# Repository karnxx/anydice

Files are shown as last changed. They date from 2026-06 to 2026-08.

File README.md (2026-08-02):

# Anydice
so this is a dice which can basically roll any number, it uses a xiao esp32c3, an oled, mpu 6040. u can set the max dice roll possibility and then shake and roll it like normal to produce a randomly generated number.

i made this project as my dnd dices wud get lost alot, and it couldnt roll some numbers, and using traditional rng online is distracting.

# WORKING
- so with the button you can set the max digit to roll. then u can shake the dice and actually roll it(mpu6050) to produce a final number on the oled, which is a random number between 0 and tht max digit. 

# PCB
- custom pcb via kicad, files [here](https://github.com/karnxx/anydice/tree/main/pcb)
- the pcb is mounted in the dice via screws, and the oled is mounted on the pcb with screws and spacers.




# [CAD](https://gmail4855044.autodesk360.com/g/shares/SH90d2dQT28d5b602811d05a79f94586e235)
- cadded via fusion360, files [here](https://github.com/karnxx/anydice/tree/main/cad)





# BOM
- bom is [here](https://docs.google.com/spreadsheets/d/12x69VHwHTzA7m8ty_oVYzZqYExIBdv50qRqhHhF5CHE/edit?usp=sharing)


| Part | Qty | Cost (₹) | Link |
|---|-----:|---:|---|
| xiaoesp32c3 | 1 | 146.00 | https://robocraze.com/products/esp32-c3-mini-development-board-unsoldered |
| mpu6040 | 1 | 154.00 | https://robocraze.com/products/mpu-6050-triple-axis-accelerometer-gyroscope-module |
| right angle tactile pushbutton | 1 | 10.00 | https://probots.co.in/mini-push-switch-right-angled.html |
| tp4056 battery management | 1 | 36.00 | https://evelta.com/tp4056x-42-esop8-lithium-ion-battery-management-1a-ic-sop-8-ep/ |
| 250mah 3.7v li-ion | 1 | 126.00 | https://probots.co.in/3-7v-250mah-lipo-battery-502030-open-ended.html |
| capacitor 470uF | 1 | 5.00 | https://quartzcomponents.com/products/470-%C2%B5f-25v-radial-electrolytic-capacitor-through-hole |
| schottky diode | 4 | 3.00 | https://quartzcomponents.com/products/1n5819-shottky-barrier-diode |
| capacitor 0.1uF | 2 | 20.00 | https://quartzcomponents.com/products/10000-pf-0-1uf-ceramic-capacitor |
| resistor 4.7kΩ | 1 | 6.00 | https://quartzcomponents.com/products/4-7k-ohm-1-4-watt-resistor |
| OLED 1.3" 128×64 | 1 | 270.00 | https://robocraze.com/products/1-3in-oled-display |
| PCB | 1 | 1022.61 | — |
| **Total** |  | **1798.61** |  |

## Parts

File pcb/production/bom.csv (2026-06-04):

Designator | Footprint | Quantity | Value | LCSC Part #
BT1 | PinHeader_1x02_P2.54mm_Vertical | 1 | Battery
C0.1ΜF2, C0.1ΜF3 | C_Disc_D3.0mm_W1.6mm_P2.50mm | 2 | C
C470ΜF1 | CP_Radial_D8.0mm_P3.50mm | 1 | C
D1, D2, D3, D4 | D_DO-41_SOD81_P10.16mm_Horizontal | 4 | 1N5819
J1 | PinHeader_1x02_P2.54mm_Vertical | 1 | Conn_01x02
R4.8 | R_Axial_DIN0207_L6.3mm_D2.5mm_P7.62mm_Horizontal | 1 | R
SW2 | SW_Tactile_SPST_Angled_PTS645Vx31-2LFS | 1 | SW_SPST
U1 | module_mpu6050 | 1 | module_mpu6050
U2 | xiao_esp32c3 | 1 | XIAO ESP32C3
U3 | ER_OLEDM0.91_1x-I2C | 1 | ER_OLEDM0.91_1x-I2C
U4 | SOIC-8-1EP_3.9x4.9mm_P1.27mm_EP2.41x3.3mm | 1 | TP4056-42-ESOP8

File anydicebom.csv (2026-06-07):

part | qty | cost | link
xiaoesp32c3 | 1 | 146 | https://robocraze.com/products/esp32-c3-mini-development-board-unsoldered?variant=48465411506400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
mpu6040 | 1 | 154 | https://robocraze.com/products/mpu-6050-triple-axis-accelerometer-gyroscope-module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
right angle tactile pushbutton | 1 | 10 | https://probots.co.in/mini-push-switch-right-angled.html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
tp4056 battery management | 1 | 36 | https://evelta.com/tp4056x-42-esop8-lithium-ion-battery-management-1a-ic-sop-8-ep/?sku=129-TP4056X-42-ESOP8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
250mah 3.7v lion | 1 | 126 | https://probots.co.in/3-7v-250mah-lipo-battery-502030-open-ended.html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
capacitor 470uf | 1 | 5 | https://quartzcomponents.com/products/470-%C2%B5f-25v-radial-electrolytic-capacitor-through-hole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
schtottky diode | 4 | 3 | https://quartzcomponents.com/products/1n5819-shottky-barrier-diode?variant=31898114556039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
capacitor 0.1uf | 2 | 20 | https://quartzcomponents.com/products/10000-pf-0-1uf-ceramic-capacitor?variant=31898110197895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
resistor 4.8 | 1 | 6 | https://quartzcomponents.com/products/4-7k-ohm-1-4-watt-resistor?variant=31898015236231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
oled 1.3" 128x64 | 1 | 270 | https://robocraze.com/products/1-3in-oled-display?variant=40192586842265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
pcb | 1 | 1022.6115
 |  | 1798.6115

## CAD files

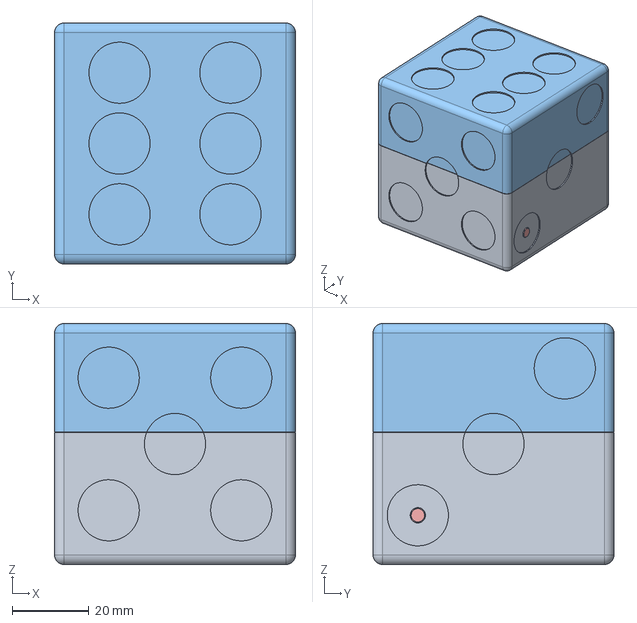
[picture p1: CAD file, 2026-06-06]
cad/3dp/stp/anydice.step
63.0 x 63.0 x 63.0 mm

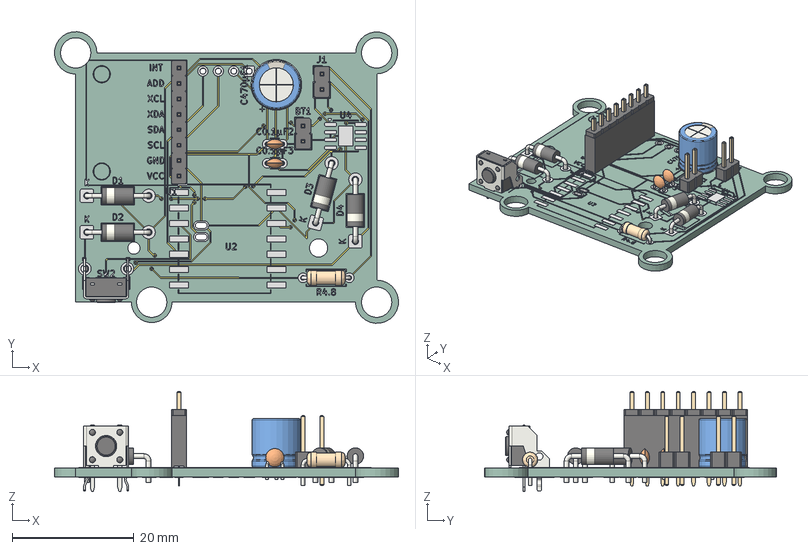
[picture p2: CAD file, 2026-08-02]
cad/anydicepcb.step
56.6 x 48.0 x 16.5 mm
D_DO-41_SOD81_P10.16mm_Horizontal_4 x 4
PinHeader_1x08_P254mm_Vertical
PinSocket_1x08_P2.54mm_Vertical_1
CP_Radial_D80mm_P350mm
SW_Tactile_SPST_Angled_PTS645Vx31-2LFS_1
PinHeader_1x02_P254mm_Vertical x 2
C_Disc_D30mm_W16mm_P250mm x 2
R_Axial_DIN0207_L63mm_D25mm_P762mm_Horizontal
anydice_copper
anydice_pad
anydice_via
anydice_silkscreen
anydice_silkscreen_1
anydice_PCB

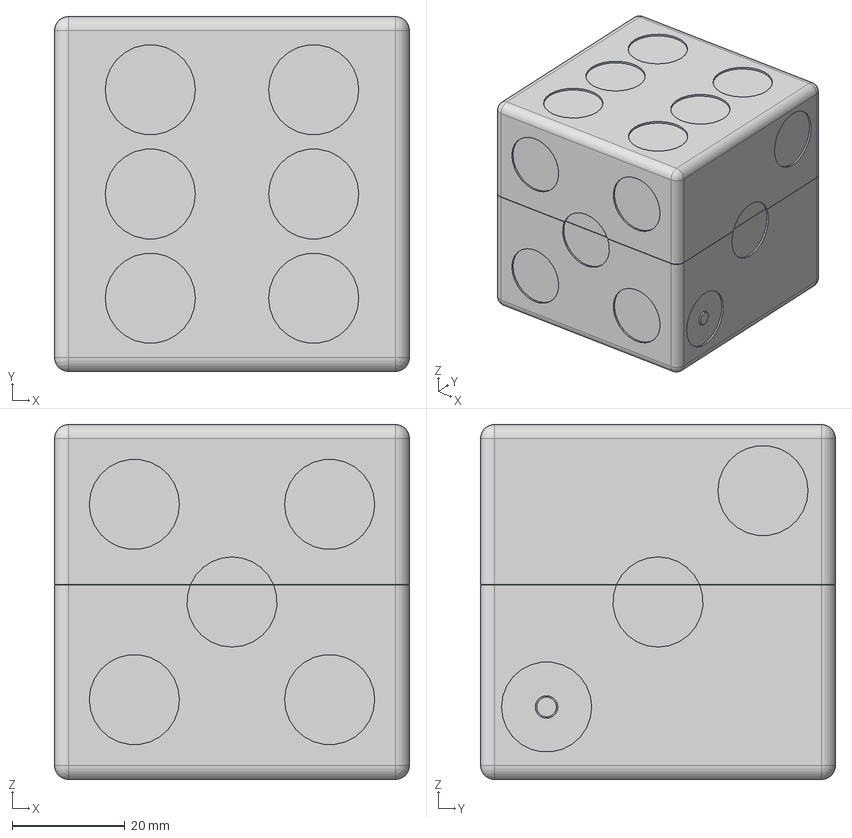
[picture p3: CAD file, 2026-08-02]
cad/anydice.step
63.0 x 63.0 x 63.0 mm
AZ-Delivery - OLED13 IIC
MPU6050
D_DO-41_SOD81_P10.16mm_Horizontal_4 x 4
PinHeader_1x08_P254mm_Vertical
PinSocket_1x08_P2.54mm_Vertical_1
CP_Radial_D80mm_P350mm
SW_Tactile_SPST_Angled_PTS645Vx31-2LFS_1
PinHeader_1x02_P254mm_Vertical x 2
C_Disc_D30mm_W16mm_P250mm x 2
R_Axial_DIN0207_L63mm_D25mm_P762mm_Horizontal
anydice_copper
anydice_pad
anydice_via
anydice_silkscreen
anydice_silkscreen_1
anydice_PCB

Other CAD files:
cad/3dp/stl/anydice.stl
cad/Untitled.f3z

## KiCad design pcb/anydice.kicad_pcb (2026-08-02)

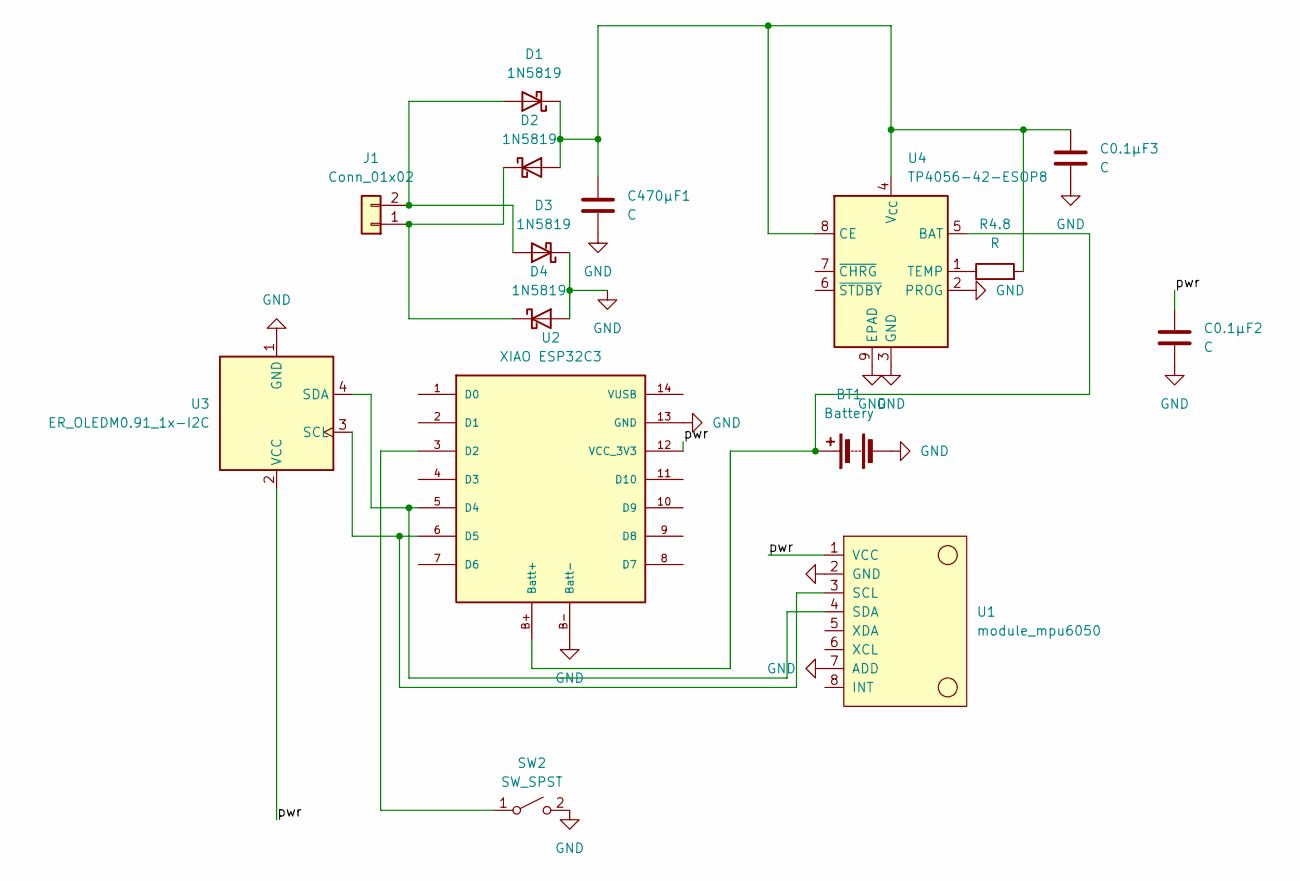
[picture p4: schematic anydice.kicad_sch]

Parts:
BT1: Battery; PinHeader_1x02_P2.54mm_Vertical
C0.1µF2, C0.1µF3: C; C_Disc_D3.0mm_W1.6mm_P2.50mm
C470µF1: C; CP_Radial_D8.0mm_P3.50mm
D1, D2, D3, D4: 1N5819; D_DO-41_SOD81_P10.16mm_Horizontal
J1: Conn_01x02; PinHeader_1x02_P2.54mm_Vertical
R4.8: R; R_Axial_DIN0207_L6.3mm_D2.5mm_P7.62mm_Horizontal
SW2: SW_SPST; SW_Tactile_SPST_Angled_PTS645Vx31-2LFS
U1: module_mpu6050
U2: XIAO ESP32C3; xiao_esp32c3
U3: ER_OLEDM0.91_1x-I2C
U4: TP4056-42-ESOP8; SOIC-8-1EP_3.9x4.9mm_P1.27mm_EP2.41x3.3mm

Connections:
/pwr: C0.1µF2.1, U1.1 (VCC), U2.12 (VCC_3V3), U3.2 (VCC)
GND: BT1.2 (-), C0.1µF2.2, C0.1µF3.2, C470µF1.2, D3.1 (K), D4.2 (A), SW2.2 (B), U1.2 (GND), U1.7 (ADD), U2.13 (GND), U2.B- (Batt-), U3.1 (GND), U4.2 (PROG), U4.3 (GND), U4.9 (EPAD)
unnamed: BT1.1 (+), U2.B+ (Batt+), U4.5 (BAT)
unnamed: D1.2 (A), D3.2 (A), J1.2
unnamed: C0.1µF3.1, C470µF1.1, D1.1 (K), D2.2 (A), R4.8.2, U4.4 (V_{CC}), U4.8 (CE)
unnamed: D2.1 (K), D4.1 (K), J1.1
unnamed: SW2.1 (A), U2.3 (D2)
unnamed: U1.3 (SCL), U2.6 (D5), U3.3 (SCL)
unnamed: U1.4 (SDA), U2.5 (D4), U3.4 (SDA)
unnamed: R4.8.1, U4.1 (TEMP)

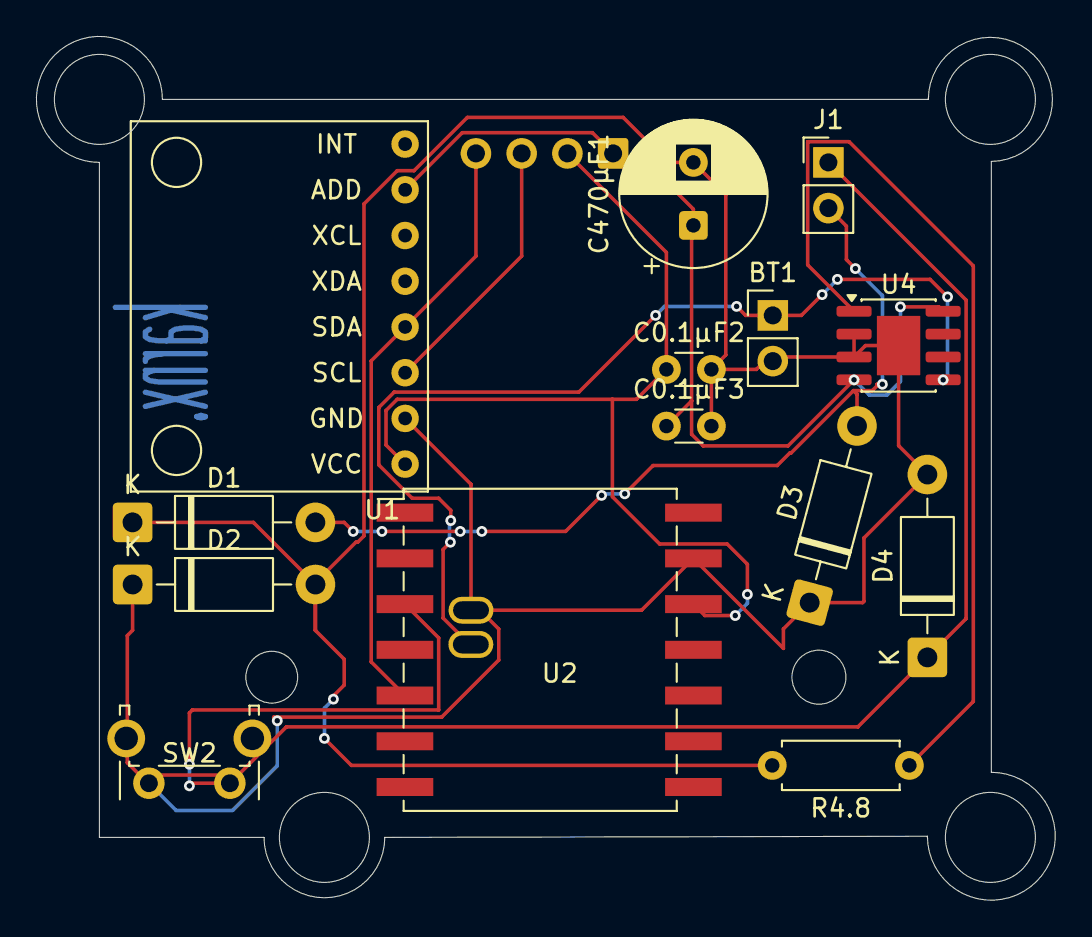
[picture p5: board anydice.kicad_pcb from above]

Board: 2 copper layers, 56.6 x 48.0 mm, 15 parts (1 on the bottom side), 10 nets.

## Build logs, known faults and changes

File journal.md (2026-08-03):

# anydice

basically a digital dice, with rng and u can roll.

# 2026-08-03: made holes in the pcb for oled mounting

**Total time spent: 0.5 hours**

i made holes on the pcb such that an oled can be fitted with spacers. if my oled's dimensions are different(india) i could drill hole.  


# 2026-06-06: finished the anydice cad

**Total time spent: 2 hours**

so i finished the cad. the d6 dice, the numbers are represented by dots, and the 1 dot has the oled which will be covered by a tinted glass piece. also added a button to the 3 dot side to change the value of the thing. then i made a slot to join the top with the bottom part. you can super glue or acetone welt the parts when everything is working. also added like a ring part whereyou can zip tie the battery.




https://lapse.hackclub.com/timelapse/Tcjek8nn16Q6

# 2026-06-06: redid the pcb

**Total time spent: 1.5 hours**

i redid the pcb, to center the oled and i also started with the cad. and instead of 2 coils, ill use 1 coil. i added mounting holes to the cad part. the product will look like a d6 dice, and will have an oled on 1 side.
 


i forgot to record some lol (the pcb and the starting cad.)
https://lapse.hackclub.com/timelapse/vR5lwHKckMRE

# 2026-06-04: Made the anydice pcb

**Total time spent: 2 hours**

anydice is a dice that can be set to any number and rolled for rng. it takes physical shaking movements via mpu6050, and u can set the max number from a button. today, i made the pcb,which is using a xiao esp32c3 as the brain of the pcb, mpu6050 for shaking detection, 1.3" oled for the numbers, and a generic switch. this i an idea i made myself, as i am a dnd dm. i also added a linear induction generator, which is a magnet moving from one fixed thick copper solenoid to another in a line, which generates electricity, exactly what u wud see in those shaking flashlight thingeys, which i thought were very cool. ill make a sphere with id 60mm, and add a weight to the bottom and a flat side. maybe i might make this into like a dropship product





https://lapse.hackclub.com/timelapse/OYcW0P9m1Et4

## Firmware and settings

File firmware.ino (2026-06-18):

#include <Wire.h>
#include <Adafruit_GFX.h>
#include <Adafruit_SH110X.h>
#include <MPU6050_light.h>

#define SCREEN_W   128
#define SCREEN_H   64
#define OLED_ADDR  0x3C

Adafruit_SH1106G display(SCREEN_W, SCREEN_H, &Wire, -1);
MPU6050 mpu(Wire);

#define BTN_PIN         3
#define DEBOUNCE_MS     40
#define DOUBLE_TAP_MS   350
#define HOLD_MS         600
#define HOLD_REPEAT_MS  150

#define SHAKE_THRESHOLD  1.8f
#define SHAKE_SETTLE_MS  600

enum Mode { ROLL_MODE, SET_MODE };

int   maxNum      = 20;
int   lastRoll    = 0;
Mode  currentMode = ROLL_MODE;
bool  rolling     = false;

unsigned long rollStartMs    = 0;
unsigned long lastShakeMs    = 0;
unsigned long btnDownMs      = 0;
unsigned long lastTapMs      = 0;
unsigned long lastHoldRepeat = 0;

bool btnPressed    = false;
bool btnWasPressed = false;
bool holdFired     = false;
bool seedDone      = false;

int tapCount = 0;

void setup() {
  Serial.begin(115200);

  pinMode(BTN_PIN, INPUT_PULLUP);
  Wire.begin(4, 5);

  if (!display.begin(OLED_ADDR, true)) {
    Serial.println("OLED init failed");
    while (true) delay(100);
  }

  display.clearDisplay();
  display.setTextColor(SH110X_WHITE);
  showSplash();

  byte mpuStatus = mpu.begin();
  if (mpuStatus != 0) {
    Serial.print("MPU error: ");
    Serial.println(mpuStatus);
    showError("MPU6050\nNot Found");
    while (true) delay(100);
  }

  mpu.calcOffsets();
  seedRNG();
  showRollScreen();
}

void loop() {
  mpu.update();
  handleButton();
  handleShake();

  if (rolling) {
    animateRoll();
    if (millis() - lastShakeMs > SHAKE_SETTLE_MS) {
      finishRoll();
    }
  }
}

void handleShake() {
  if (currentMode != ROLL_MODE) return;

  float ax = mpu.getAccX();
  float ay = mpu.getAccY();
  float az = mpu.getAccZ();
  float mag = sqrt(ax*ax + ay*ay + az*az);
  float delta = abs(mag - 1.0f);

  if (delta > SHAKE_THRESHOLD) {
    lastShakeMs = millis();
    if (!rolling) {
      rolling = true;
      rollStartMs = millis();
    }
  }
}

void finishRoll() {
  rolling  = false;
  lastRoll = random(1, maxNum + 1);
  showRollScreen();
}

void handleButton() {
  bool raw = (digitalRead(BTN_PIN) == LOW);

  static bool debounced = false;
  static unsigned long lastChange = 0;

  if (raw != debounced) {
    if (millis() - lastChange > DEBOUNCE_MS) {
      debounced  = raw;
      lastChange = millis();
      onBtnChange(debounced);
    }
  }

  if (currentMode == SET_MODE && debounced && holdFired) {
    if (millis() - lastHoldRepeat > HOLD_REPEAT_MS) {
      lastHoldRepeat = millis();
      changeMax(+10);
    }
  }

  if (tapCount == 1 && (millis() - lastTapMs > DOUBLE_TAP_MS)) {
    tapCount = 0;
    onSingleTap();
  }
}

void onBtnChange(bool pressed) {
  if (pressed) {
    btnDownMs      = millis();
    holdFired      = false;
    lastHoldRepeat = millis();
  } else {
    unsigned long held = millis() - btnDownMs;

    if (held >= HOLD_MS && !holdFired) {
      if (currentMode == SET_MODE) {
        holdFired = true;
        changeMax(+10);
      }
    }

    if (!holdFired) {
      unsigned long now = millis();
      if (tapCount == 1 && (now - lastTapMs <= DOUBLE_TAP_MS)) {
        tapCount = 0;
        onDoubleTap();
      } else {
        tapCount  = 1;
        lastTapMs = now;
      }
    }

    if (held >= HOLD_MS) holdFired = true;
  }
}

void onSingleTap() {
  if (currentMode == SET_MODE) {
    changeMax(+1);
  }
}

void onDoubleTap() {
  if (currentMode == ROLL_MODE) {
    currentMode = SET_MODE;
    showSetScreen();
  } else {
    currentMode = ROLL_MODE;
    showRollScreen();
  }
}

void changeMax(int delta) {
  maxNum += delta;
  if (maxNum < 2)    maxNum = 2;
  if (maxNum > 9999) maxNum = 9999;
  showSetScreen();
}

void showSplash() {
  display.clearDisplay();
  display.setTextSize(2);
  display.setCursor(20, 10);
  display.print("AnyDice");
  display.setTextSize(1);
  display.setCursor(22, 38);
  display.print("Shake to roll!");
  display.setCursor(10, 52);
  display.print("DblTap: set max");
  display.display();
  delay(2000);
}

void showRollScreen() {
  display.clearDisplay();

  display.setTextSize(1);
  display.setCursor(0, 0);
  display.print("d");
  display.print(maxNum);
  display.setCursor(80, 0);
  display.print("ROLL");
  display.drawLine(0, 10, 127, 10, SH110X_WHITE);

  if (lastRoll == 0) {
    display.setTextSize(2);
    display.setCursor(14, 24);
    display.print("Shake me!");
  } else {
    String s = String(lastRoll);
    int textSize = (lastRoll < 100) ? 4 : 3;
    display.setTextSize(textSize);
    int x = (SCREEN_W - s.length() * 6 * textSize) / 2;
    display.setCursor(max(0, x), 18);
    display.print(lastRoll);
  }

  display.drawLine(0, 53, 127, 53, SH110X_WHITE);
  display.setTextSize(1);
  display.setCursor(0, 56);
  display.print("DblTap to set max");
  display.display();
}

void showSetScreen() {
  display.clearDisplay();

  display.setTextSize(1);
  display.setCursor(0, 0);
  display.print("SET MAX NUMBER");
  display.drawLine(0, 10, 127, 10, SH110X_WHITE);

  String s = String(maxNum);
  int textSize = (maxNum < 100) ? 4 : 3;
  display.setTextSize(textSize);
  int x = (SCREEN_W - (int)s.length() * 6 * textSize) / 2;
  display.setCursor(max(0, x), 18);
  display.print(maxNum);

  display.drawLine(0, 53, 127, 53, SH110X_WHITE);
  display.setTextSize(1);
  display.setCursor(0, 56);
  display.print("Tap:+1  Hold:+10  Dbl:OK");
  display.display();
}

void animateRoll() {
  static unsigned long lastFrame = 0;
  if (millis() - lastFrame < 80) return;
  lastFrame = millis();

  int n = random(1, maxNum + 1);

  display.clearDisplay();
  display.setTextSize(1);
  display.setCursor(0, 0);
  display.print("d");
  display.print(maxNum);
  display.setCursor(70, 0);
  display.print("ROLLING..");
  display.drawLine(0, 10, 127, 10, SH110X_WHITE);

  String s = String(n);
  int textSize = (maxNum < 100) ? 4 : 3;
  display.setTextSize(textSize);
  int x = (SCREEN_W - (int)s.length() * 6 * textSize) / 2;
  display.setCursor(max(0, x), 18);
  display.print(n);
  display.display();
}

void showError(const char* msg) {
  display.clearDisplay();
  display.setTextSize(1);
  display.setCursor(0, 0);
  display.print("ERROR:");
  display.setCursor(0, 16);
  display.print(msg);
  display.display();
}

void seedRNG() {
  uint32_t seed = 0;
  for (int i = 0; i < 64; i++) {
    mpu.update();
    seed ^= (uint32_t)(mpu.getAccX() * 100000) << (i % 3);
    seed ^= (uint32_t)(mpu.getAccY() * 100000) << ((i + 1) % 5);
    seed ^= (uint32_t)(mpu.getAccZ() * 100000) << ((i + 2) % 7);
    seed ^= esp_random();
    delay(5);
  }
  randomSeed(seed);
}

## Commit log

2026-06-04 added the pcb stuff
    production folder from kicad
    [bom.csv, designators.csv, positions.csv]
2026-06-04 added more pcb parts
    added .kicak_pcb, prl, pro, sch.
    [anydice.kicad_pcb, anydice.kicad_sch, bom.csv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]
2026-06-04 Create .step
    added step file of the pcb
    [.step]
2026-06-06 added add the files and cadfiles
    [.step, anydice.kicad_pcb, anydice.step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]
2026-06-07 Rename anydicebom - Sheet1.csv to anydicebom.csv
    [anydicebom.csv]
2026-06-15 added cads
    [anydice.f3z, anydicecad.stl, anydicefull.f3z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]
2026-08-02 upd 3d files
    [Untitled.f3z, Untitled.step, anydice.f3z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]
2026-08-03 Revise journal entry for OLED PCB modifications
    Updated journal entry with new date and details about PCB modifications for OLED mounting. Adjusted total time spent.
